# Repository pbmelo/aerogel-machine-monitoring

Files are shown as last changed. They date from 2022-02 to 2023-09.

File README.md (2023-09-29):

# aerogel-machine-monitoring

This repository is meant to be a place where I'm able to control and keep my
files for a remote monitoring system I have developed for a critical point drying machine.

## Note

The files hosted here are under active development and have some minor issues.
I expect to keep updating the repository with improvements as well as a detailed
guide on how to use and reproduce it yourself.

## What is required to build a similar system

1. An Arduino or similar controller
2. As many thermocouples as wanted (0 to 5)
3. Adafruit's max31856 thermocouple current amplifier (one per thermocouple)
4. As many pressure transducers that operate in a 4..20 mA fashion as wanted
   (0 to 5)
5. As many electrically operated pneumatic valves as wanted (0-4)
6. Generic 5V relays (one per pneumatic valve)
7. A computer that will host the web interface and talk to the Arduino board (if
   a web interface is desired)

## Contents

This repository contains

1. Source code for the Arduino board to monitor temperature and pressure
   sensors, as well as control relays
2. Required files for a system on a chip (such as Raspberry Pi) or any other
   computer, such as the following:
3. A systemd service that communicates with the Arduino to read its output and
   write it to a file, to be later used by the web server
4. Source code for the web interface that controls the Arduino.  Namely, read
   the output file, display the data to the user interface, grab user commands
   from the interface and send them to the Arduino
5. Instructions on how to wire the system and set the software up

### To do

My future plans consist of

1. Improve the performance and overall user experience of the web interface
2. Write a detailed tutorial on how to set everything up
3. Make a Raspberry Pi, other arm32/64, as well as an x86_64 image with
   everything pre configured, such that the end user will just have to clone
   them to disk
4. Upload pictures of the web interface as well as printed circuit, together
   with a short usage manual (it's all very intuitive, really!)
5. Design and upload a 3D printed case for the whole system

### Images

Here's how the system looks after being soldered and assembled

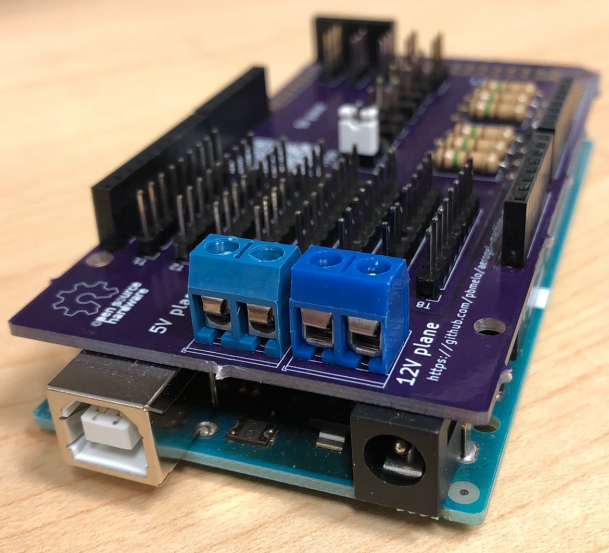
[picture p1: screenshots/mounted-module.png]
Photo of the assembled system


## LICENSE

Copyright (C) 2022 pbmelo

This program is free software: you can redistribute it and/or modify it under
the terms of the GNU General Public License as published by the Free Software
Foundation, either version 3 of the License, or (at your option) any later
version.

This program is distributed in the hope that it will be useful, but WITHOUT ANY
WARRANTY; without even the implied warranty of MERCHANTABILITY or FITNESS FOR A
PARTICULAR PURPOSE. See the GNU General Public License for more details.

You should have received a copy of the GNU General Public License along with
this program. If not, see <https://www.gnu.org/licenses/>.

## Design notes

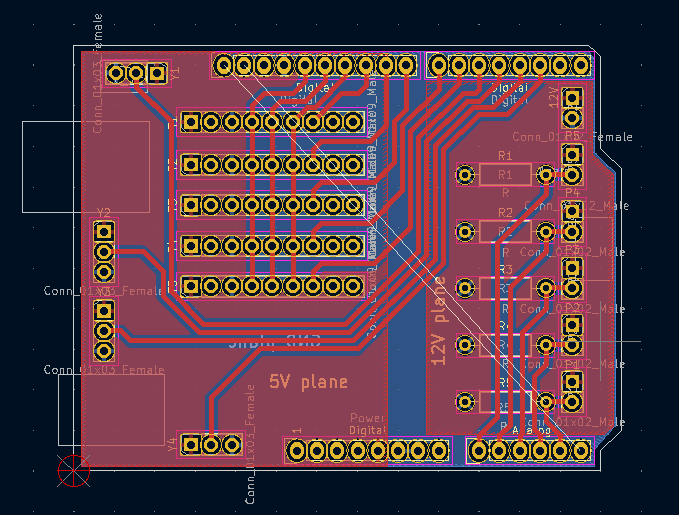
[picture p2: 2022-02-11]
screenshots/aerogel_shield_pcb_schematics.png

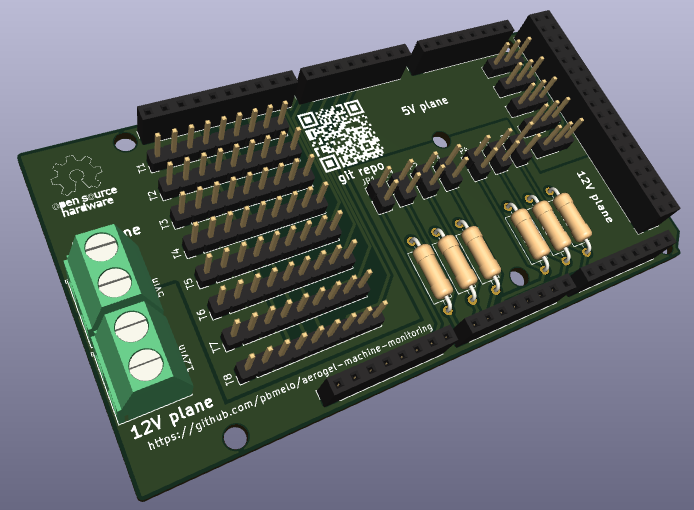
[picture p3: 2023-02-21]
screenshots/arduino_mega_cpd_shield.png

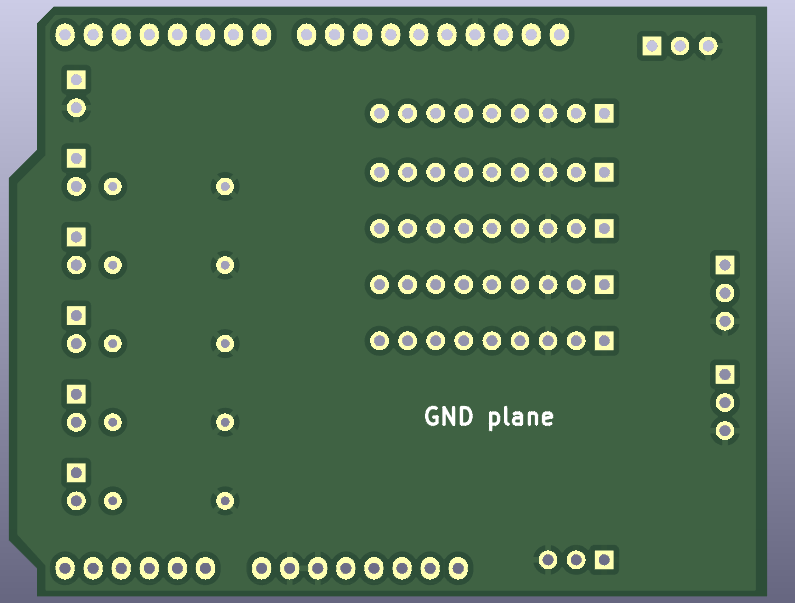
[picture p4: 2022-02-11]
screenshots/aerogel_shield_back.png

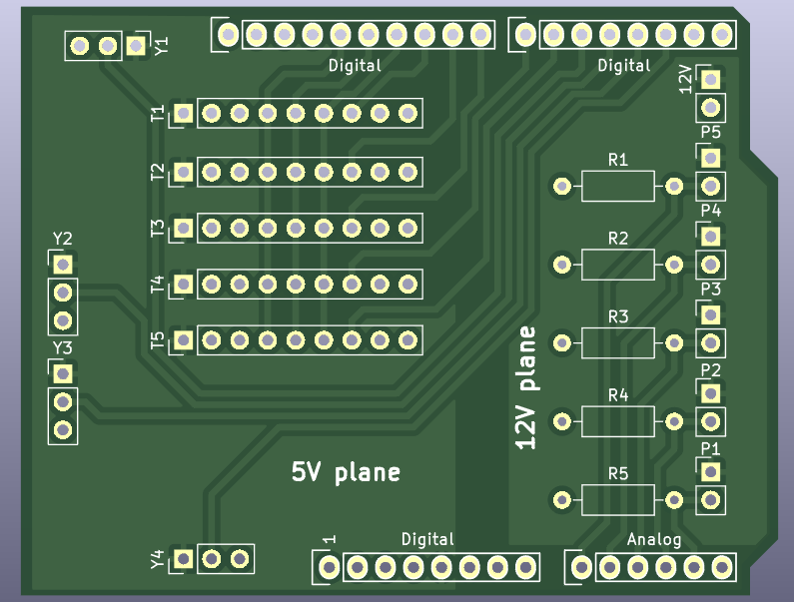
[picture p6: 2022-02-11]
screenshots/aerogel_shield.png

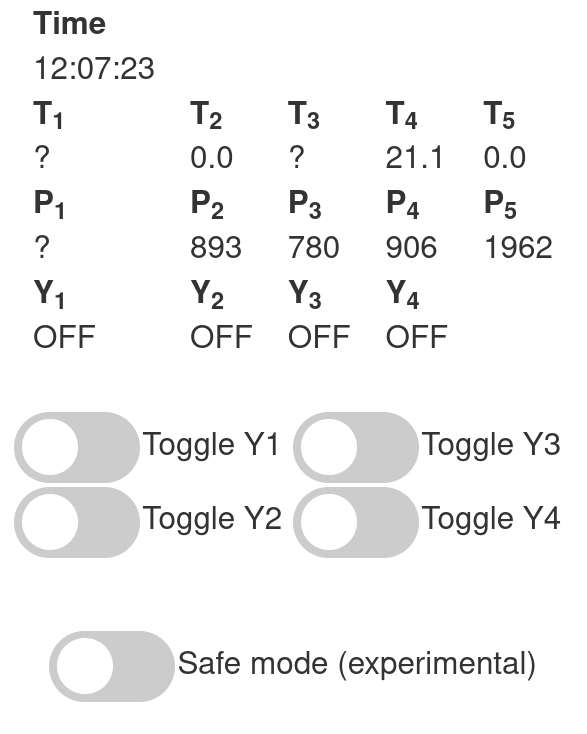
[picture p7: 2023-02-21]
screenshots/web_interface.png

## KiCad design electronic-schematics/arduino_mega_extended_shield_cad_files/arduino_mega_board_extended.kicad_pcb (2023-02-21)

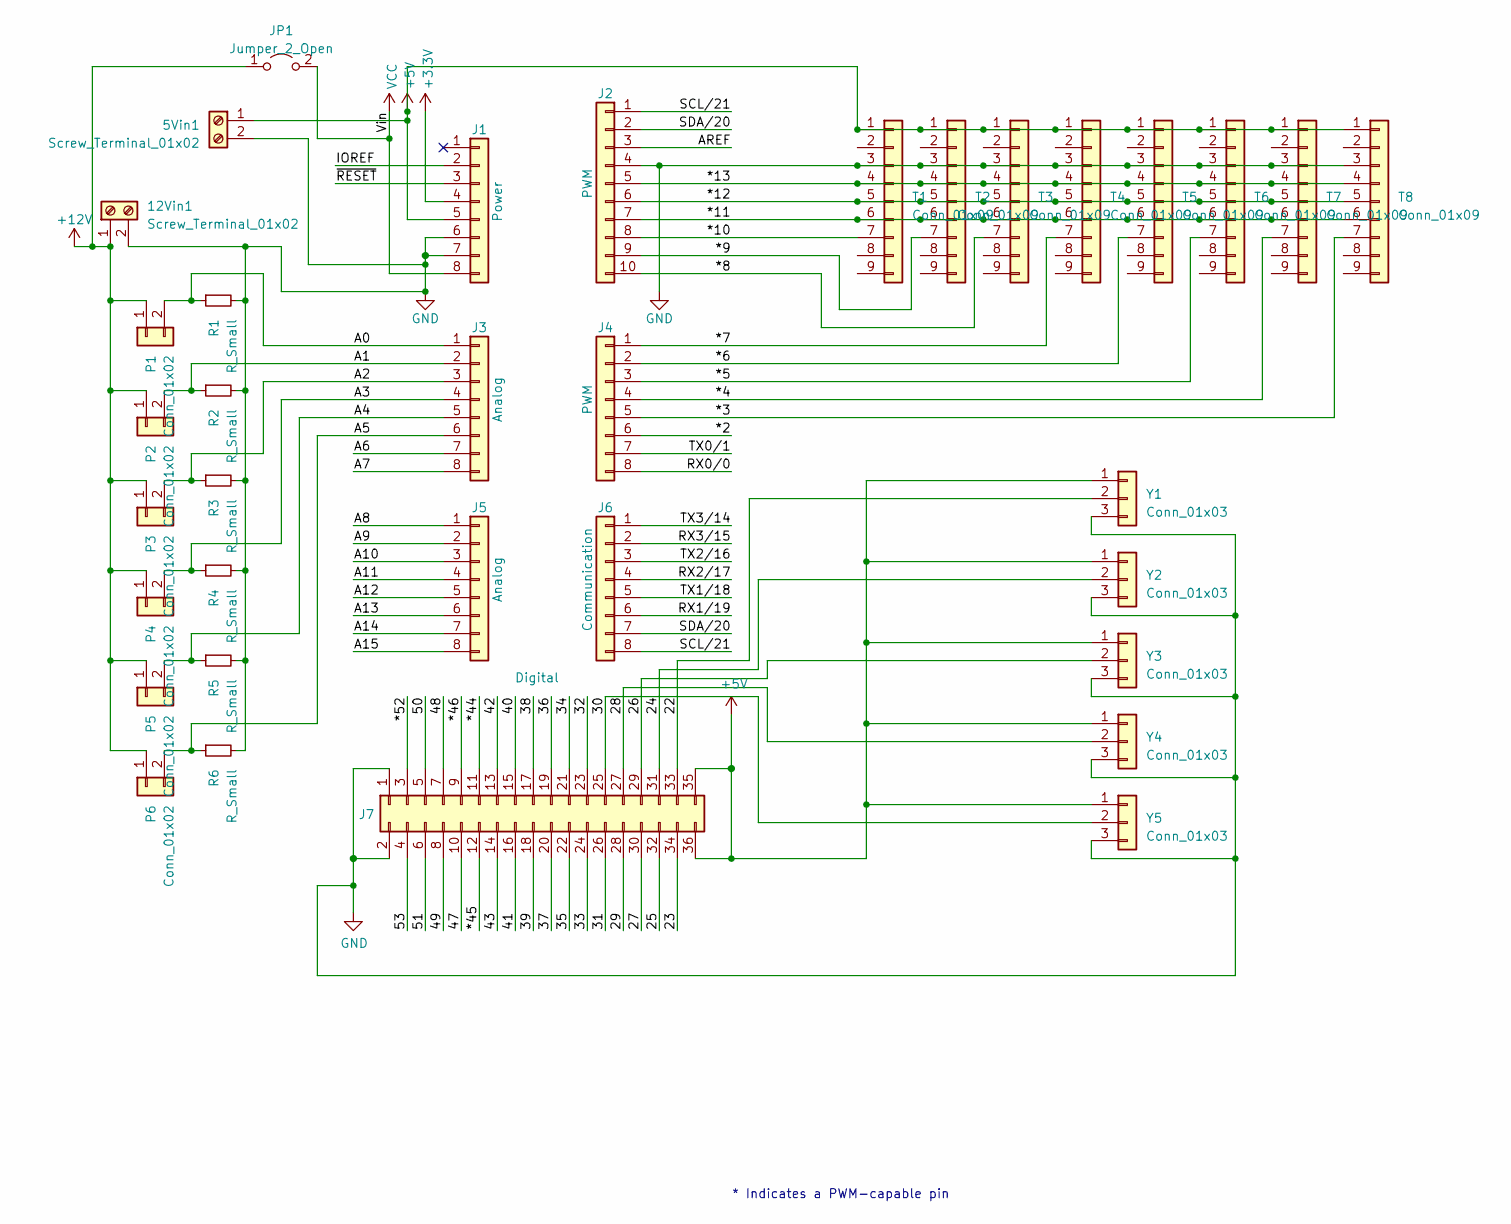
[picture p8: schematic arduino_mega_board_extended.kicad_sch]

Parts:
5Vin1, 12Vin1: Screw_Terminal_01x02; TerminalBlock_Phoenix_MKDS-1,5-2-5.08_1x02_P5.08mm_Horizont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
J1: Power; PinSocket_1x08_P2.54mm_Vertical
J2: PWM; PinSocket_1x10_P2.54mm_Vertical
J3, J5: Analog; PinSocket_1x08_P2.54mm_Vertical
J4: PWM; PinSocket_1x08_P2.54mm_Vertical
J6: Communication; PinSocket_1x08_P2.54mm_Vertical
J7: Digital; PinSocket_2x18_P2.54mm_Vertical
JP1: Jumper_2_Open; PinHeader_1x02_P2.54mm_Vertical
P1, P2, P3, P4, P5, P6: Conn_01x02; PinHeader_1x02_P2.54mm_Vertical
R1, R2, R3, R4, R5, R6: R_Small; R_Axial_DIN0309_L9.0mm_D3.2mm_P12.70mm_Horizontal
T1, T2, T3, T4, T5, T6, T7, T8: Conn_01x09; PinHeader_1x09_P2.54mm_Vertical
Y1, Y2, Y3, Y4, Y5: Conn_01x03; PinHeader_1x03_P2.54mm_Vertical

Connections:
+3V3: J1.4
+5V: 5Vin1.1, J1.5, J7.35, J7.36, T1.1, T2.1, T3.1, T4.1, T5.1, T6.1, T7.1, T8.1, Y1.1, Y2.1, Y3.1, Y4.1, Y5.1; also elsewhere on the board
+12V: 12Vin1.1, JP1.1 (A), P1.1, P2.1, P3.1, P4.1, P5.1, P6.1; also elsewhere on the board
/23: J7.34
/25: J7.32
/27: J7.30
/29: J7.28
/31: J7.26
/32: J7.23
/33: J7.24
/34: J7.21
/35: J7.22
/36: J7.19
/37: J7.20
/38: J7.17
/39: J7.18
/40: J7.15
/41: J7.16
/42: J7.13
/43: J7.14
/47: J7.10
/48: J7.7
/49: J7.8
/50: J7.5
/51: J7.6
/53: J7.4
/*2: J4.6
/*3: J4.5, T8.7
/*4: J4.4, T7.7
/*5: J4.3, T6.7
/*6: J4.2, T5.7
/*7: J4.1, T4.7
/*8: J2.10, T3.7
/*9: J2.9, T2.7
/*10: J2.8, T1.7
/*11: J2.7, T1.6, T2.6, T3.6, T4.6, T5.6, T6.6, T7.6, T8.6
/*12: J2.6, T1.5, T2.5, T3.5, T4.5, T5.5, T6.5, T7.5, T8.5
/*13: J2.5, T1.4, T2.4, T3.4, T4.4, T5.4, T6.4, T7.4, T8.4
/*44: J7.11
/*45: J7.12
/*46: J7.9
/*52: J7.3
/A0: J3.1, P1.2, R1.1
/A1: J3.2, P2.2, R2.1
/A2: J3.3, P3.2, R3.1
/A3: J3.4, P4.2, R4.1
/A4: J3.5, P5.2, R5.1
/A5: J3.6, P6.2, R6.1
/A6: J3.7
/A7: J3.8
/A8: J5.1
/A9: J5.2
/A10: J5.3
/A11: J5.4
/A12: J5.5
/A13: J5.6
/A14: J5.7
/A15: J5.8
/AREF: J2.3
/IOREF: J1.2
/RX0/0: J4.8
/RX1/19: J6.6
/RX2/17: J6.4
/RX3/15: J6.2
/SCL/21: J2.1, J6.8
/SDA/20: J2.2, J6.7
/TX0/1: J4.7
/TX1/18: J6.5
/TX2/16: J6.3
/TX3/14: J6.1
/~RESET: J1.3
GND: 5Vin1.2, 12Vin1.2, J1.6, J1.7, J2.4, J7.1, J7.2, R1.2, R2.2, R3.2, R4.2, R5.2, R6.2, T1.3, T2.3, T3.3, T4.3, T5.3, T6.3, T7.3, T8.3, Y1.3, Y2.3, Y3.3, Y4.3, Y5.3; also elsewhere on the board
VCC: J1.8, JP1.2 (B)

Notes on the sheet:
* Indicates a PWM-capable pin

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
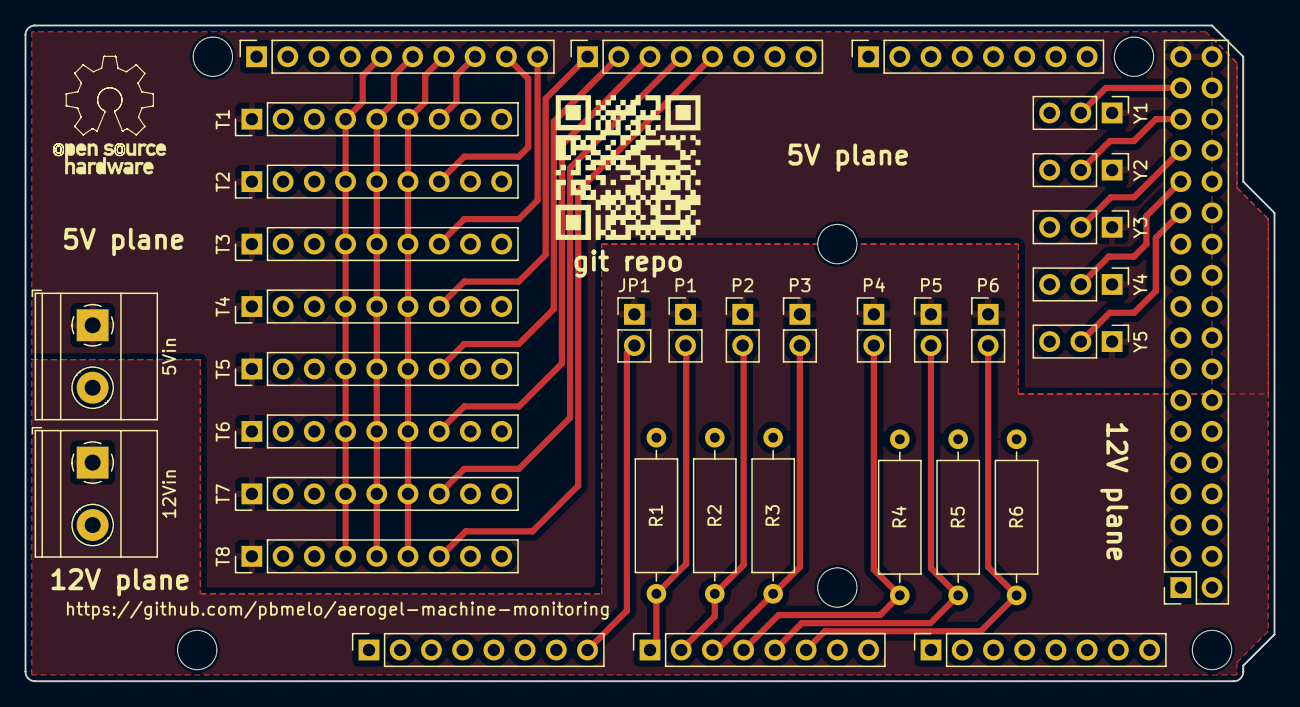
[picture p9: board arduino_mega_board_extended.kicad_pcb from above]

Board: 2 copper layers, 101.6 x 53.3 mm, 43 parts (1 on the bottom side), 28 nets.

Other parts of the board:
5Vin, 12Vin: Screw_Terminal_01x02; TerminalBlock_Phoenix_MKDS-1,5-2-5.08_1x02_P5.08mm_Horizont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
MH1, MH2, MH3, MH4, MH5, MH6: MountingHole_3.2mm
git repo: LOGO; qrcode-aerogel-github-kicad-footprint-small
git repo#2: LOGO; qrcode-aerogel-github-kicad-footprint-small

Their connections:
+5V: 5Vin.1; also elsewhere on the board
+12V: 12Vin.1; also elsewhere on the board
GND: 5Vin.2, 12Vin.2; also elsewhere on the board

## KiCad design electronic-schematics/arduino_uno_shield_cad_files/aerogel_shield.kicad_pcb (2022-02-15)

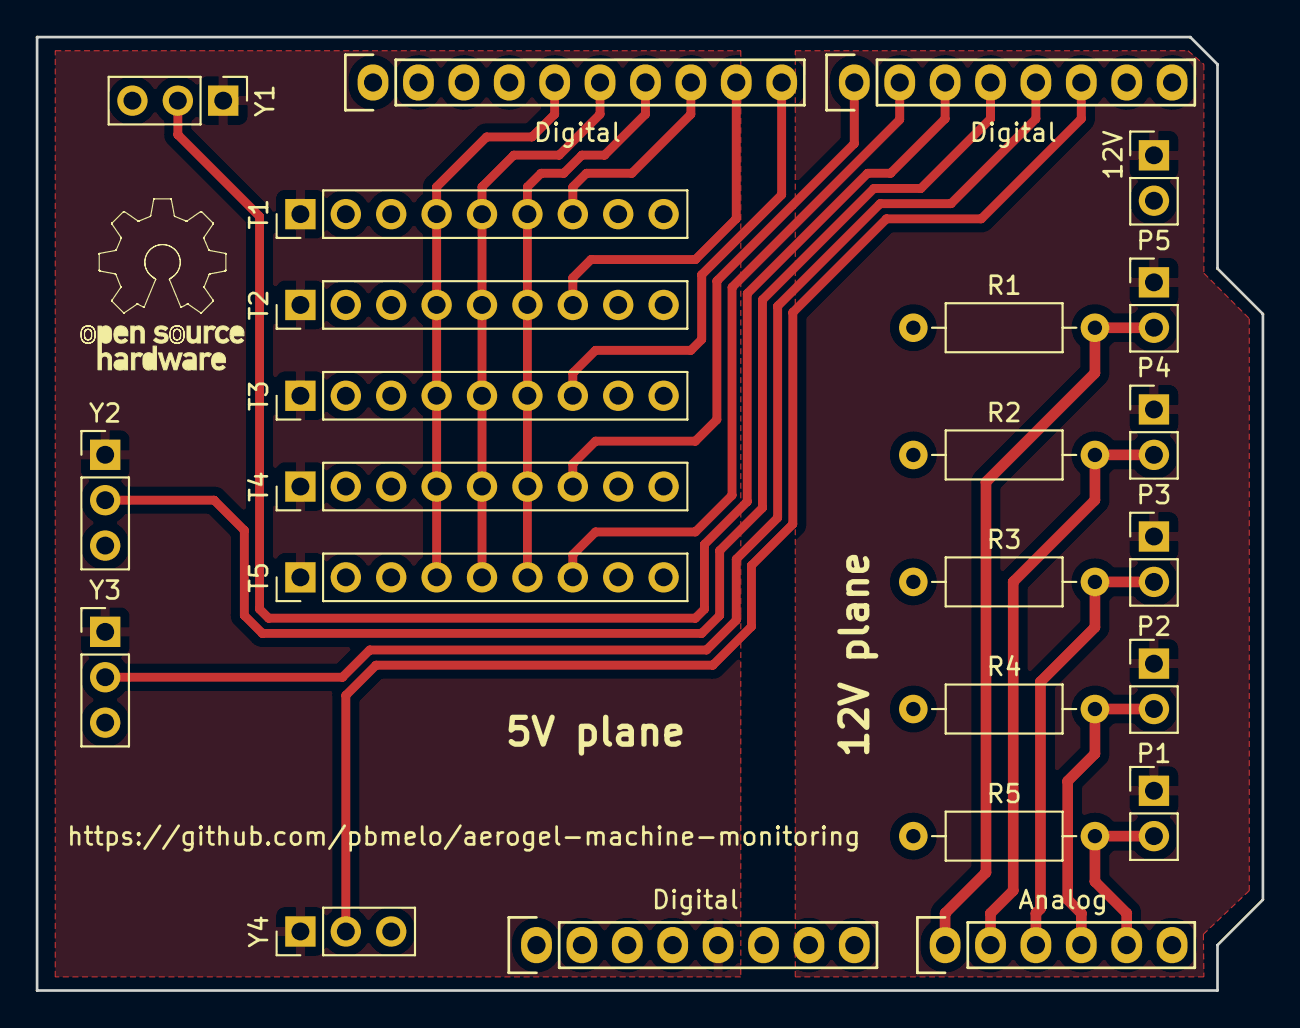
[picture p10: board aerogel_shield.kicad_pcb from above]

Board: 2 copper layers, 68.6 x 53.3 mm, 24 parts (0 on the bottom side), 21 nets.

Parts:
12V: Conn_01x02_Female; PinHeader_1x02_P2.54mm_Vertical
Analog: Analog; Socket_Strip_Arduino_1x06
Digital: Power; Socket_Strip_Arduino_1x08
Digital#2: Digital; Socket_Strip_Arduino_1x10
Digital#3: Digital; Socket_Strip_Arduino_1x08
P1, P2, P3, P4, P5: Conn_01x02_Male; PinHeader_1x02_P2.54mm_Vertical
R1, R2, R3, R4, R5: R; R_Axial_DIN0207_L6.3mm_D2.5mm_P10.16mm_Horizontal
T1, T2, T3, T4, T5: Conn_01x09_Male; PinHeader_1x09_P2.54mm_Vertical
Y1, Y2, Y3, Y4: Conn_01x03_Female; PinHeader_1x03_P2.54mm_Vertical

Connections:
+5V: Digital.5, T1.1, T2.1, T3.1, T4.1, T5.1, Y1.1, Y2.1, Y3.1, Y4.1
+12V: 12V.1, P1.1, P2.1, P3.1, P4.1, P5.1
/2: Digital#3.6, Y4.2
/3(**): Digital#3.5, Y3.2
/4: Digital#3.4, Y2.2
/5(**): Digital#3.3, Y1.2
/6(**): Digital#3.2, T5.7
/7: Digital#3.1, T4.7
/8: Digital#2.10, T3.7
/9(**): Digital#2.9, T2.7
/10(**/SS): Digital#2.8, T1.7
/11(**/MOSI): Digital#2.7, T1.6, T2.6, T3.6, T4.6, T5.6
/12(MISO): Digital#2.6, T1.5, T2.5, T3.5, T4.5, T5.5
/13(SCK): Digital#2.5, T1.4, T2.4, T3.4, T4.4, T5.4
/A0: Analog.1, P5.2, R1.2
/A1: Analog.2, P4.2, R2.2
/A2: Analog.3, P3.2, R3.2
/A3: Analog.4, P2.2, R4.2
/A4(SDA): Analog.5, Digital#2.2, P1.2, R5.2
/A5(SCL): Analog.6, Digital#2.1
GND: 12V.2, Digital.6, Digital.7, Digital#2.4, R1.1, R2.1, R3.1, R4.1, R5.1, T1.3, T2.3, T3.3, T4.3, T5.3, Y1.3, Y2.3, Y3.3, Y4.3

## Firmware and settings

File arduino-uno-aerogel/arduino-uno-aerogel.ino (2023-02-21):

// Basic example using one-shot measurement.
// The call to readThermocoupleTemperature() is blocking for O(100ms)

#include <Adafruit_MAX31856.h>

// Use software SPI: CS, DI, DO, CLK
Adafruit_MAX31856 maxthermo = Adafruit_MAX31856(10, 11, 12, 13);
Adafruit_MAX31856 maxthermo2 = Adafruit_MAX31856(9, 11, 12, 13);
Adafruit_MAX31856 maxthermo3 = Adafruit_MAX31856(8, 11, 12, 13);
Adafruit_MAX31856 maxthermo4 = Adafruit_MAX31856(7, 11, 12, 13);
Adafruit_MAX31856 maxthermo5 = Adafruit_MAX31856(6, 11, 12, 13);
//Adafruit_MAX31856 maxthermo = Adafruit_MAX31856(47, 32, 46, 32);
//Adafruit_MAX31856 maxthermo4 = Adafruit_MAX31856(38, 36, 34, 32);
//Adafruit_MAX31856 maxthermo3 = Adafruit_MAX31856(30, 28, 26, 24);
//Adafruit_MAX31856 maxthermo4 = Adafruit_MAX31856(38, 36, 34, 32);
// use hardware SPI, just pass in the CS pin
/*Adafruit_MAX31856 maxthermo = Adafruit_MAX31856(10);*/

double temp, temp2, temp3, temp4, temp5;
double CJ_temp, CJ_temp2, CJ_temp3, CJ_temp4, CJ_temp5;

char strBuf[150];

//int led = 43;
int relay1 = 2;
int relay2 = 3;
int relay3 = 4;
int relay4 = 5;

String sdata="";

int pressure_sensor1=A0;
int pressure_sensor2=A1;
int pressure_sensor3=A2;
int pressure_sensor4=A3;
int pressure_sensor5=A4;

int pressure_output1, pressure_output2, pressure_output3, pressure_output4, pressure_output5;
int actual_pressure1, actual_pressure2, actual_pressure3, actual_pressure4, actual_pressure5;

int valve1status=0, valve2status=0, valve3status=0, valve4status=0;

int safetystatus=0;
const int safety_threshold=1350;
const int lower_safety_threshold=1250;

int get_pressure(int pressure_pin) {
  int n_loop = 500;
  int i_loop;
  int analog_pressure_single;
  long analog_pressure_avg = 0;

  for(i_loop=0;i_loop<n_loop;i_loop++) {
    analog_pressure_single = analogRead(pressure_pin);
    analog_pressure_avg += analog_pressure_single;
  }
  analog_pressure_avg /= n_loop;

  return analog_pressure_avg;
  //return map(analog_pressure_avg,0,510,0,810);
  //return map_pressure(analog_pressure_avg);

}

/* 
 *  Pressure | analogRead
 *  500      | 437
 *  600      | 462
 *  700      | 500
 *  800      | 540
 *  900      | 570
 *  1000     | 602
 *  1100     | 643
 *  1200     | 680
 *  1300     | 710
 *  y = y0 + (x - x0)*(y1 - y0)/(x1 - x0)
 */
int map_pressure(int analog_read) {
  float actual_pressure;
  float analog_float = (float) analog_read;
  //For 330 ohms:
  /*if (analog_read<437) {
    //actual_pressure = map(analog_read,0,437,0,500);
    actual_pressure = analog_float*500/437;
  } else if (analog_read<462) {
    //actual_pressure = map(analog_read,437,462,500,600);
    actual_pressure = (analog_float-437)*(600-500)/(462-437) + 500;
  } else if (analog_read<500) {
    //actual_pressure = map(analog_read,462,500,600,700);
    actual_pressure = (analog_float-462)*(700-600)/(500-462) + 600;
  } else if (analog_read<540) {
    //actual_pressure = map(analog_read,500,540,700,800);
    actual_pressure = (analog_float-500)*(800-700)/(540-500) + 700;
  } else if (analog_read<570) {
    //actual_pressure = map(analog_read,540,570,800,900);
    actual_pressure = (analog_float-540)*(900-800)/(570-540) + 800;
  } else if (analog_read<602) {
    //actual_pressure = map(analog_read,570,602,900,1000);
    actual_pressure = (analog_float-570)*(1000-900)/(602-570) + 900;
  } else if (analog_read<643) {
    //actual_pressure = map(analog_read,602,643,1000,1100);
    actual_pressure = (analog_float-602)*(1100-1000)/(643-602) + 1000;
  } else if (analog_read<680) {
    //actual_pressure = map(analog_read,643,680,1100,1200);
    actual_pressure = (analog_float-643)*(1200-1100)/(680-643) + 1100;
  } else if (analog_read<710) {
    //actual_pressure = map(analog_read,680,710,1200,1300);
    actual_pressure = (analog_float-680)*(1300-1200)/(710-680) + 1200;
  } else {
    actual_pressure = map(analog_read,680,710,1200,1300);
  }*/

  //For 150 ohms:
  if (analog_read<111) {
    actual_pressure = map(analog_read,0,111,0,15);
    //actual_pressure = analog_float*654/209;
  } else if (analog_read<209) {
    actual_pressure = map(analog_read,111,209,15,654);
    //actual_pressure = analog_float*654/209;
  } else if (analog_read<216) {
    actual_pressure = map(analog_read,209,216,654,705);
    //actual_pressure = (analog_float-437)*(600-500)/(462-437) + 500;
  } else if (analog_read<223) {
    actual_pressure = map(analog_read,216,223,705,751);
    //actual_pressure = (analog_float-462)*(700-600)/(500-462) + 600;
  } else if (analog_read<228) {
    actual_pressure = map(analog_read,223,228,751,780);
    //actual_pressure = (analog_float-500)*(800-700)/(540-500) + 700;
  } else if (analog_read<240) {
    actual_pressure = map(analog_read,228,240,780,852);
    //actual_pressure = (analog_float-540)*(900-800)/(570-540) + 800;
  //Values from now on are more reliable:
  } else if (analog_read<247) {
    actual_pressure = map(analog_read,240,247,852,900);
    //actual_pressure = (analog_float-570)*(1000-900)/(602-570) + 900;
  } else if (analog_read<255) {
    actual_pressure = map(analog_read,247,255,900,950);
    //actual_pressure = (analog_float-570)*(1000-900)/(602-570) + 900;
  } else if (analog_read<263) {
    actual_pressure = map(analog_read,255,263,950,1000);
    //actual_pressure = (analog_float-602)*(1100-1000)/(643-602) + 1000;
  } else if (analog_read<270) {
    actual_pressure = map(analog_read,263,270,1000,1050);
    //actual_pressure = (analog_float-643)*(1200-1100)/(680-643) + 1100;
  } else if (analog_read<279) {
    actual_pressure = map(analog_read,270,279,1050,1100);
    //actual_pressure = (analog_float-680)*(1300-1200)/(710-680) + 1200;
  } else if (analog_read<287) {
    actual_pressure = map(analog_read,279,287,1100,1150);
    //actual_pressure = (analog_float-680)*(1300-1200)/(710-680) + 1200;
  } else if (analog_read<294) {
    actual_pressure = map(analog_read,287,294,1150,1200);
    //actual_pressure = (analog_float-680)*(1300-1200)/(710-680) + 1200;
  } else if (analog_read<303) {
    actual_pressure = map(analog_read,294,303,1200,1250);
    //actual_pressure = (analog_float-680)*(1300-1200)/(710-680) + 1200;
  } else if (analog_read<310) {
    actual_pressure = map(analog_read,303,310,1250,1300);
    //actual_pressure = (analog_float-680)*(1300-1200)/(710-680) + 1200;
  } else if (analog_read<319) {
    actual_pressure = map(analog_read,310,319,1300,1350);
    //actual_pressure = (analog_float-680)*(1300-1200)/(710-680) + 1200;
  } else if (analog_read<326) {
    actual_pressure = map(analog_read,319,326,1350,1400);
    //actual_pressure = (analog_float-680)*(1300-1200)/(710-680) + 1200;
  } else if (analog_read<333) {
    actual_pressure = map(analog_read,326,333,1400,1450);
    //actual_pressure = (analog_float-680)*(1300-1200)/(710-680) + 1200;
  } else if (analog_read<340) {
    actual_pressure = map(analog_read,333,340,1450,1500);
    //actual_pressure = (analog_float-680)*(1300-1200)/(710-680) + 1200;
  } else if (analog_read<348) {
    actual_pressure = map(analog_read,340,348,1500,1550);
    //actual_pressure = (analog_float-680)*(1300-1200)/(710-680) + 1200;
  } else if (analog_read<357) {
    actual_pressure = map(analog_read,348,357,1550,1600);
    //actual_pressure = (analog_float-680)*(1300-1200)/(710-680) + 1200;
  } else if (analog_read<373) {
    actual_pressure = map(analog_read,357,373,1600,1700);
    //actual_pressure = (analog_float-680)*(1300-1200)/(710-680) + 1200;
  } else if (analog_read<380) {
    actual_pressure = map(analog_read,373,380,1700,1750);
    //actual_pressure = (analog_float-680)*(1300-1200)/(710-680) + 1200;
  } else if (analog_read<389) {
    actual_pressure = map(analog_read,380,389,1750,1800);
    //actual_pressure = (analog_float-680)*(1300-1200)/(710-680) + 1200;
  } else if (analog_read<397) {
    actual_pressure = map(analog_read,389,397,1800,1850);
    //actual_pressure = (analog_float-680)*(1300-1200)/(710-680) + 1200;
  } else if (analog_read<404) {
    actual_pressure = map(analog_read,397,404,1850,1900);
    //actual_pressure = (analog_float-680)*(1300-1200)/(710-680) + 1200;
  } else if (analog_read<412) {
    actual_pressure = map(analog_read,404,412,1900,1950);
    //actual_pressure = (analog_float-680)*(1300-1200)/(710-680) + 1200;
  } else if (analog_read<420) {
    actual_pressure = map(analog_read,412,420,1950,2000);
    //actual_pressure = (analog_float-680)*(1300-1200)/(710-680) + 1200;
  } else if (analog_read<429) {
    actual_pressure = map(analog_read,420,429,2000,2050);
    //actual_pressure = (analog_float-680)*(1300-1200)/(710-680) + 1200;
  } else if (analog_read<435) {
    actual_pressure = map(analog_read,429,435,2050,2100);
    //actual_pressure = (analog_float-680)*(1300-1200)/(710-680) + 1200;
  } else if (analog_read<442) {
    actual_pressure = map(analog_read,435,442,2100,2150);
    //actual_pressure = (analog_float-680)*(1300-1200)/(710-680) + 1200;
  } else if (analog_read<454) {
    actual_pressure = map(analog_read,442,454,2150,2200);
    //actual_pressure = (analog_float-680)*(1300-1200)/(710-680) + 1200;
  } else if (analog_read<467) {
    actual_pressure = map(analog_read,454,467,2200,2250);
    //actual_pressure = (analog_float-680)*(1300-1200)/(710-680) + 1200;
  } else if (analog_read<480) {
    actual_pressure = map(analog_read,467,480,2250,2300);
    //actual_pressure = (analog_float-680)*(1300-1200)/(710-680) + 1200;
  } else if (analog_read<497) {
    actual_pressure = map(analog_read,480,497,2300,2350);
    //actual_pressure = (analog_float-680)*(1300-1200)/(710-680) + 1200;
  } else if (analog_read<513) {
    actual_pressure = map(analog_read,497,513,2350,2400);
    //actual_pressure = (analog_float-680)*(1300-1200)/(710-680) + 1200;
  } else if (analog_read<531) {
    actual_pressure = map(analog_read,513,531,2400,2450);
    //actual_pressure = (analog_float-680)*(1300-1200)/(710-680) + 1200;
  } else if (analog_read<546) {
    actual_pressure = map(analog_read,531,546,2450,2500);
    //actual_pressure = (analog_float-680)*(1300-1200)/(710-680) + 1200;
  } else {
    actual_pressure = map(analog_read,531,546,2450,2500);
  }

  return (int) actual_pressure;

}

void setup() {
  Serial.begin(115200);
  while (!Serial) delay(10);
  Serial.println("MAX31856 thermocouple test");

  maxthermo.begin();
  maxthermo2.begin();
  maxthermo3.begin();
  maxthermo4.begin();

  maxthermo.setThermocoupleType(MAX31856_TCTYPE_K);
  maxthermo2.setThermocoupleType(MAX31856_TCTYPE_K);
  maxthermo3.setThermocoupleType(MAX31856_TCTYPE_K);
  maxthermo4.setThermocoupleType(MAX31856_TCTYPE_K);

  Serial.print("Thermocouple 1 type: ");
  switch (maxthermo.getThermocoupleType() ) {
    case MAX31856_TCTYPE_B: Serial.println("B Type"); break;
    case MAX31856_TCTYPE_E: Serial.println("E Type"); break;
    case MAX31856_TCTYPE_J: Serial.println("J Type"); break;
    case MAX31856_TCTYPE_K: Serial.println("K Type"); break;
    case MAX31856_TCTYPE_N: Serial.println("N Type"); break;
    case MAX31856_TCTYPE_R: Serial.println("R Type"); break;
    case MAX31856_TCTYPE_S: Serial.println("S Type"); break;
    case MAX31856_TCTYPE_T: Serial.println("T Type"); break;
    case MAX31856_VMODE_G8: Serial.println("Voltage x8 Gain mode"); break;
    case MAX31856_VMODE_G32: Serial.println("Voltage x8 Gain mode"); break;
    default: Serial.println("Unknown"); break;
  }

  Serial.print("Thermocouple 2 type: ");
  switch (maxthermo2.getThermocoupleType() ) {
    case MAX31856_TCTYPE_B: Serial.println("B Type"); break;
    case MAX31856_TCTYPE_E: Serial.println("E Type"); break;
    case MAX31856_TCTYPE_J: Serial.println("J Type"); break;
    case MAX31856_TCTYPE_K: Serial.println("K Type"); break;
    case MAX31856_TCTYPE_N: Serial.println("N Type"); break;
    case MAX31856_TCTYPE_R: Serial.println("R Type"); break;
    case MAX31856_TCTYPE_S: Serial.println("S Type"); break;
    case MAX31856_TCTYPE_T: Serial.println("T Type"); break;
    case MAX31856_VMODE_G8: Serial.println("Voltage x8 Gain mode"); break;
    case MAX31856_VMODE_G32: Serial.println("Voltage x8 Gain mode"); break;
    default: Serial.println("Unknown"); break;
  }

  Serial.print("Thermocouple 3 type: ");
  switch (maxthermo3.getThermocoupleType() ) {
    case MAX31856_TCTYPE_B: Serial.println("B Type"); break;
    case MAX31856_TCTYPE_E: Serial.println("E Type"); break;
    case MAX31856_TCTYPE_J: Serial.println("J Type"); break;
    case MAX31856_TCTYPE_K: Serial.println("K Type"); break;
    case MAX31856_TCTYPE_N: Serial.println("N Type"); break;
    case MAX31856_TCTYPE_R: Serial.println("R Type"); break;
    case MAX31856_TCTYPE_S: Serial.println("S Type"); break;
    case MAX31856_TCTYPE_T: Serial.println("T Type"); break;
    case MAX31856_VMODE_G8: Serial.println("Voltage x8 Gain mode"); break;
    case MAX31856_VMODE_G32: Serial.println("Voltage x8 Gain mode"); break;
    default: Serial.println("Unknown"); break;
  }

  Serial.print("Thermocouple 4 type: ");
  switch (maxthermo4.getThermocoupleType() ) {
    case MAX31856_TCTYPE_B: Serial.println("B Type"); break;
    case MAX31856_TCTYPE_E: Serial.println("E Type"); break;
    case MAX31856_TCTYPE_J: Serial.println("J Type"); break;
    case MAX31856_TCTYPE_K: Serial.println("K Type"); break;
    case MAX31856_TCTYPE_N: Serial.println("N Type"); break;
    case MAX31856_TCTYPE_R: Serial.println("R Type"); break;
    case MAX31856_TCTYPE_S: Serial.println("S Type"); break;
    case MAX31856_TCTYPE_T: Serial.println("T Type"); break;
    case MAX31856_VMODE_G8: Serial.println("Voltage x8 Gain mode"); break;
    case MAX31856_VMODE_G32: Serial.println("Voltage x8 Gain mode"); break;
    default: Serial.println("Unknown"); break;
  }

  Serial.print("Thermocouple 5 type: ");
  switch (maxthermo4.getThermocoupleType() ) {
    case MAX31856_TCTYPE_B: Serial.println("B Type"); break;
    case MAX31856_TCTYPE_E: Serial.println("E Type"); break;
    case MAX31856_TCTYPE_J: Serial.println("J Type"); break;
    case MAX31856_TCTYPE_K: Serial.println("K Type"); break;
    case MAX31856_TCTYPE_N: Serial.println("N Type"); break;
    case MAX31856_TCTYPE_R: Serial.println("R Type"); break;
    case MAX31856_TCTYPE_S: Serial.println("S Type"); break;
    case MAX31856_TCTYPE_T: Serial.println("T Type"); break;
    case MAX31856_VMODE_G8: Serial.println("Voltage x8 Gain mode"); break;
    case MAX31856_VMODE_G32: Serial.println("Voltage x8 Gain mode"); break;
    default: Serial.println("Unknown"); break;
  }

  pinMode(relay1,OUTPUT);
  pinMode(relay2,OUTPUT);
  pinMode(relay3,OUTPUT);
  pinMode(relay4,OUTPUT);
  pinMode(pressure_sensor1,INPUT);
  pinMode(pressure_sensor2,INPUT);
  pinMode(pressure_sensor3,INPUT);
  pinMode(pressure_sensor4,INPUT);
  pinMode(pressure_sensor5,INPUT);

// switch relays off
  digitalWrite(relay1,LOW);
  digitalWrite(relay2,LOW);
  digitalWrite(relay3,LOW);
  digitalWrite(relay4,LOW);

}

void loop() {
  // Check and print any faults
  /*uint8_t fault1 = maxthermo.readFault();
  if (fault1) {
    if (fault1 & MAX31856_FAULT_CJRANGE) Serial.println("Cold Junction Range 1 Fault");
    if (fault1 & MAX31856_FAULT_TCRANGE) Serial.println("Thermocouple Range 1 Fault");
    if (fault1 & MAX31856_FAULT_CJHIGH)  Serial.println("Cold Junction High 1 Fault");
    if (fault1 & MAX31856_FAULT_CJLOW)   Serial.println("Cold Junction Low 1 Fault");
    if (fault1 & MAX31856_FAULT_TCHIGH)  Serial.println("Thermocouple High 1 Fault");
    if (fault1 & MAX31856_FAULT_TCLOW)   Serial.println("Thermocouple Low 1 Fault");
    if (fault1 & MAX31856_FAULT_OVUV)    Serial.println("Over/Under Voltage 1 Fault");
    if (fault1 & MAX31856_FAULT_OPEN)    Serial.println("Thermocouple Open 1 Fault");
  }*/

  //Serial.print("Cold Junction 1 Temp: ");
  //Serial.println(maxthermo.readCJTemperature());
  CJ_temp = maxthermo.readCJTemperature();

  //Serial.print("Thermocouple 1 Temp: ");
  //Serial.println(maxthermo.readThermocoupleTemperature());
  temp = maxthermo.readThermocoupleTemperature();

  //Serial.print("Cold Junction 2 Temp: ");
  //Serial.println(maxthermo2.readCJTemperature());
  CJ_temp2 = maxthermo2.readCJTemperature();

  //Serial.print("Thermocouple 2 Temp: ");
  //Serial.println(maxthermo2.readThermocoupleTemperature());
  temp2 = maxthermo2.readThermocoupleTemperature();

  //Serial.print("Cold Junction 3 Temp: ");
  //Serial.println(maxthermo.readCJTemperature());
  CJ_temp3 = maxthermo3.readCJTemperature();

  //Serial.print("Thermocouple 3 Temp: ");
  //Serial.println(maxthermo.readThermocoupleTemperature());
  temp3 = maxthermo3.readThermocoupleTemperature();

  //Serial.print("Cold Junction 4 Temp: ");
  //Serial.println(maxthermo2.readCJTemperature());
  CJ_temp4 = maxthermo4.readCJTemperature();

  //Serial.print("Thermocouple 4 Temp: ");
  //Serial.println(maxthermo2.readThermocoupleTemperature());
  temp4 = maxthermo4.readThermocoupleTemperature();

  //Serial.print("Cold Junction 4 Temp: ");
  //Serial.println(maxthermo2.readCJTemperature());
  CJ_temp5 = maxthermo5.readCJTemperature();

  //Serial.print("Thermocouple 4 Temp: ");
  //Serial.println(maxthermo2.readThermocoupleTemperature());
  temp5 = maxthermo5.readThermocoupleTemperature();

//Read pressure
  pressure_output1 = get_pressure(pressure_sensor1);
  pressure_output2 = get_pressure(pressure_sensor2);
  pressure_output3 = get_pressure(pressure_sensor3);
  pressure_output4 = get_pressure(pressure_sensor4);
  pressure_output5 = get_pressure(pressure_sensor5);
//Map pressure
  actual_pressure1 = map_pressure(pressure_output1);
  actual_pressure2 = map_pressure(pressure_output2);
  actual_pressure3 = map_pressure(pressure_output3);
  actual_pressure4 = map_pressure(pressure_output4);
  actual_pressure5 = map_pressure(pressure_output5);

  Serial.print("Sensor outputs (T1,T2,T3,T4,T5,P1,P2,P3,P4,P5,Y1,Y2,Y3,Y4): ");
  Serial.print(temp);
  Serial.print(" ");
  Serial.print(temp2);
  Serial.print(" ");
  Serial.print(temp3);
  Serial.print(" ");
  Serial.print(temp4);
  Serial.print(" ");
  Serial.print(temp5);
  Serial.print(" ");
  //Serial.print(pressure_output1);
  //Serial.print("/");
  Serial.print(actual_pressure1);
  Serial.print(" ");
  //Serial.print(pressure_output2);
  //Serial.print("/");
  Serial.print(actual_pressure2);
  Serial.print(" ");
  //Serial.print(pressure_output3);
  //Serial.print("/");
  Serial.print(actual_pressure3);
  Serial.print(" ");
  //Serial.print(pressure_output4);
  //Serial.print("/");
  Serial.print(actual_pressure4);
  Serial.print(" ");
  //Serial.print(pressure_output5);
  //Serial.print("/");
  Serial.print(actual_pressure5);
  Serial.print(" ");
  Serial.print(valve1status);
  Serial.print(" ");
  Serial.print(valve2status);
  Serial.print(" ");
  Serial.print(valve3status);
  Serial.print(" ");
  Serial.print(valve4status);
  Serial.print(" ");
  Serial.println(safetystatus);

  //sprintf(strBuf, "Temperatures: %f %f\n", temp, temp2);
  //Serial.print(strBuf);

  if (safetystatus) {
    if (actual_pressure5 > safety_threshold) {
      valve1status = 0;
      digitalWrite(relay1,LOW);
    } else if (actual_pressure5 < lower_safety_threshold) { 
      valve1status = 1;
      digitalWrite(relay1,HIGH);
    }
  }

  // listen to serial input and act accordingly
  byte ch;
  if (Serial.available()) {
    ch = Serial.read();
    sdata += (char)ch;
    sdata.trim();
    // Process command in sdata.
    switch( sdata.charAt(0) ) {
      case 'p':
        safetystatus = 1;
        break;
      case 'q':
        safetystatus = 0;
        break;
      case 's':
        if (safetystatus) {
          if (actual_pressure5 < safety_threshold) {
            valve1status = 1;
            digitalWrite(relay1,HIGH);
          }
        } else {
            valve1status = 1;
            digitalWrite(relay1,HIGH);
        }
        break;
      case 't':
        valve1status = 0;
        digitalWrite(relay1,LOW);
        break;
      case 'w':
        valve2status = 1;
        digitalWrite(relay2,HIGH);
        break;
      case 'k':
        valve2status = 0;
        digitalWrite(relay2,LOW);
        break;
      case 'e':
        valve3status = 1;
        digitalWrite(relay3,HIGH);
        break;
      case 'l':
        valve3status = 0;
        digitalWrite(relay3,LOW);
        break;
      case 'c':
        valve4status = 1;
        digitalWrite(relay4,HIGH);
        break;
      case 'o':
        valve4status = 0;
        digitalWrite(relay4,LOW);
        break;
     //default: Serial.println(sdata);
    }
    sdata = ""; // Clear the string ready for the next command.
  }

  delay(500);

}

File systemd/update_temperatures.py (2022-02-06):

import time
import numpy as np
import serial
import glob

#ws_root = "/var/www/localhost/htdocs/"
ws_root = "/var/www/html/"
data_file2 = ws_root+"graphs/data.csv"
data2 = []
max_len = 20

available_devices=glob.glob('/dev/ttyACM*')
for each_device in available_devices:
    print(each_device)

ser = serial.Serial(available_devices[0], 115200, timeout=2, xonxoff=False, rtscts=False, dsrdtr=False)
ser.flushInput()
ser.flushOutput()

sensor_string = "Sensor outputs"

time_init = time.time()

while (True):
    if(ser.in_waiting):
        #data_raw = str(ser.readline())
        data_raw = ser.readline().decode('unicode_escape')
        if (sensor_string in data_raw):
            temperature1 = str(round(float(data_raw.split(" ")[-9].replace("\n","")),1))
            temperature2 = str(round(float(data_raw.split(" ")[-8].replace("\n","")),1))
            temperature3 = str(round(float(data_raw.split(" ")[-7].replace("\n","")),1))
            temperature4 = str(round(float(data_raw.split(" ")[-6].replace("\n","")),1))
            pressure1 = str(data_raw.split(" ")[-5].replace("\n",""))
            pressure2 = str(data_raw.split(" ")[-4].replace("\n",""))
            pressure3 = str(data_raw.split(" ")[-3].replace("\n",""))
            relay1 = str(data_raw.split(" ")[-2].replace("\n",""))
            relay2 = str(data_raw.split(" ")[-1].replace("\n",""))
        else:
            continue
        time_unix = time.time()
        time_std = time.ctime()
        time_fmt = time.strftime('%H:%M:%S', time.localtime(time_unix))
        #data2.append(str(time_unix-time_init)+","+str(np.cos(time_unix)))
        #data2.append(time_fmt+","+str(50.0+10.0*np.cos(time_unix)))
        data2.append(time_fmt+","+temperature1+","+temperature2+","+temperature3+","+temperature4+","+pressure1+","+pressure2+","+pressure3+","+relay1+","+relay2)
        #print(data[-1])
        print(data2[-1].rstrip())
        if (len(data2) > max_len):
            data2.pop(0)
            with open(data_file2,"w") as f_out2:
                f_out2.write("datetime,temperature1,temperature2,temperature3,temperature4,pressure1,pressure2,pressure3,relay1,relay2\n")
                for each_entry in data2:
                    f_out2.write(each_entry)
                    f_out2.write("\n")
    else:
        time.sleep(0.1)

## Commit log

2022-02-06 uploading the repository
    [aerogel_shield.kicad_pcb, aerogel_shield.kicad_sch, data.csv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]
2022-02-11 increase track width on gerber files, add screenshots, update readme
    [aerogel_shield-B_Cu.gbr, aerogel_shield-B_Silkscreen.gbr, aerogel_shield-Edge_Cuts.gbr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]
2022-02-15 improving cad files
    [aerogel_shield-B_Cu.gbr, aerogel_shield-B_Silkscreen.gbr, aerogel_shield-Edge_Cuts.gbr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]
2023-02-17 Adding Arduino Mega board CAD files, extended version with more connections for extra sensors
    [aerogel_shield-B_Cu.gbr, aerogel_shield-B_Silkscreen.gbr, aerogel_shield-Edge_Cuts.gbr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]
2023-02-21 Fixing project files for Mega shield. Adding gerber files for Mega shield. Adding screenshots for Mega shield and web interface. Changing some file names.
    [arduino_mega_board_extended.kicad_pcb, arduino_mega_board_extended.kicad_sch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]
2023-02-21 Updating web interface. Updating arduino code for uno shield.
2023-05-02 adding images of the complete pcb
2023-05-02 adding photo of fully assembled printed circuit board to readme
